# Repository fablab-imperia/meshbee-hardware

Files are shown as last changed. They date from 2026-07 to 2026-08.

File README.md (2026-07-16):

# 🐝 MeshBee - Sistema di Monitoraggio Arnie

Hardware

```
meshbee-hardware/
├── 3d-print/     # File CAD per stampa 3D (FreeCAD)
└── pcb/          # Schemi elettrici e documentazione
```

## 📄 Licenza

Questo progetto è distribuito sotto licenza CERN-OHL-S

## 👥 Team

Sviluppato per apicoltori e monitoraggio ambientale.

---

**Fatto con ❤️ per le api** 🐝

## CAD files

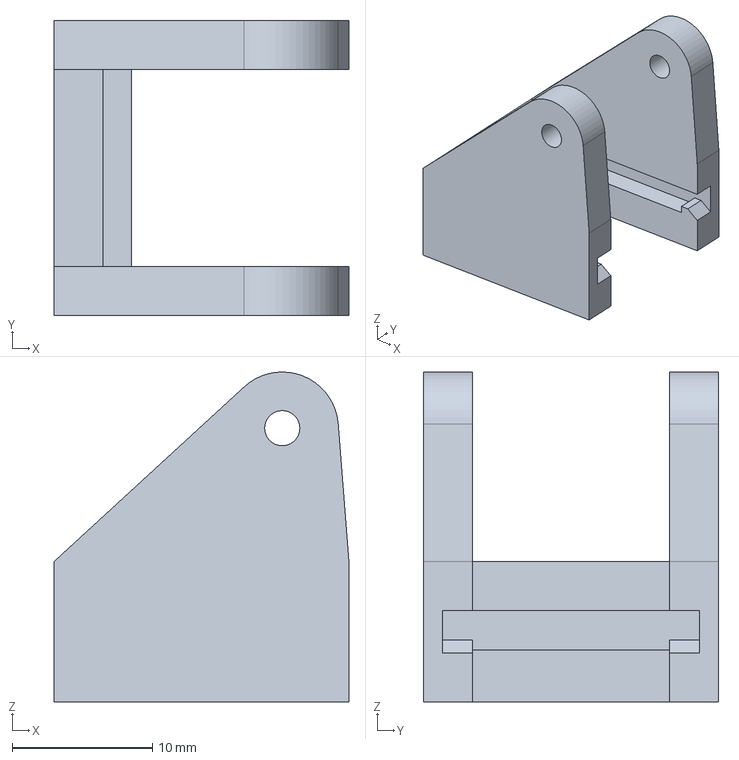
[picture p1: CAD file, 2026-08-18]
3d-print/sensor.FCStd
21.0 x 21.0 x 23.5 mm

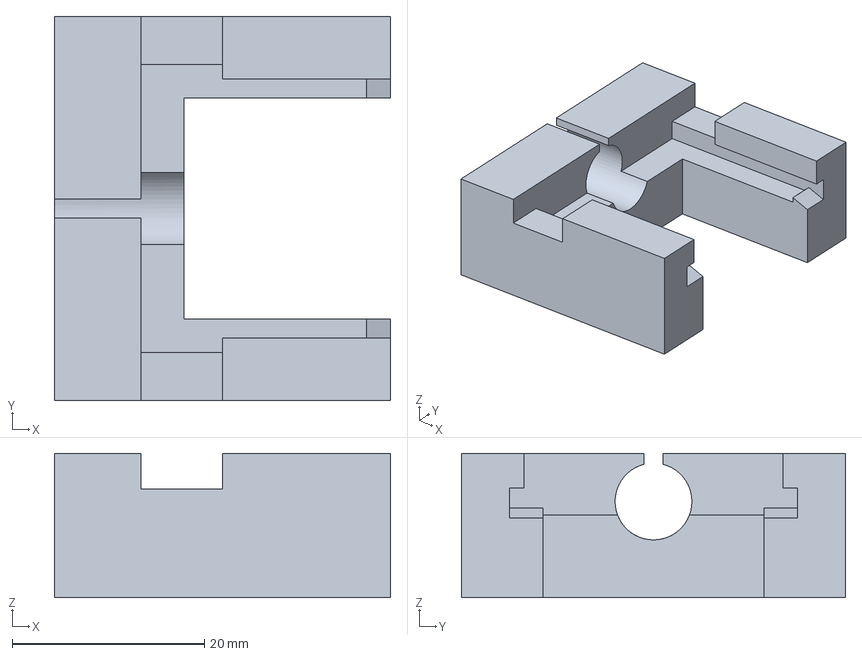
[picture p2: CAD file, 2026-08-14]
3d-print/cell_holder.FCStd
35.0 x 40.0 x 15.0 mm

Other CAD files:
3d-print/beehive modules.FCStd

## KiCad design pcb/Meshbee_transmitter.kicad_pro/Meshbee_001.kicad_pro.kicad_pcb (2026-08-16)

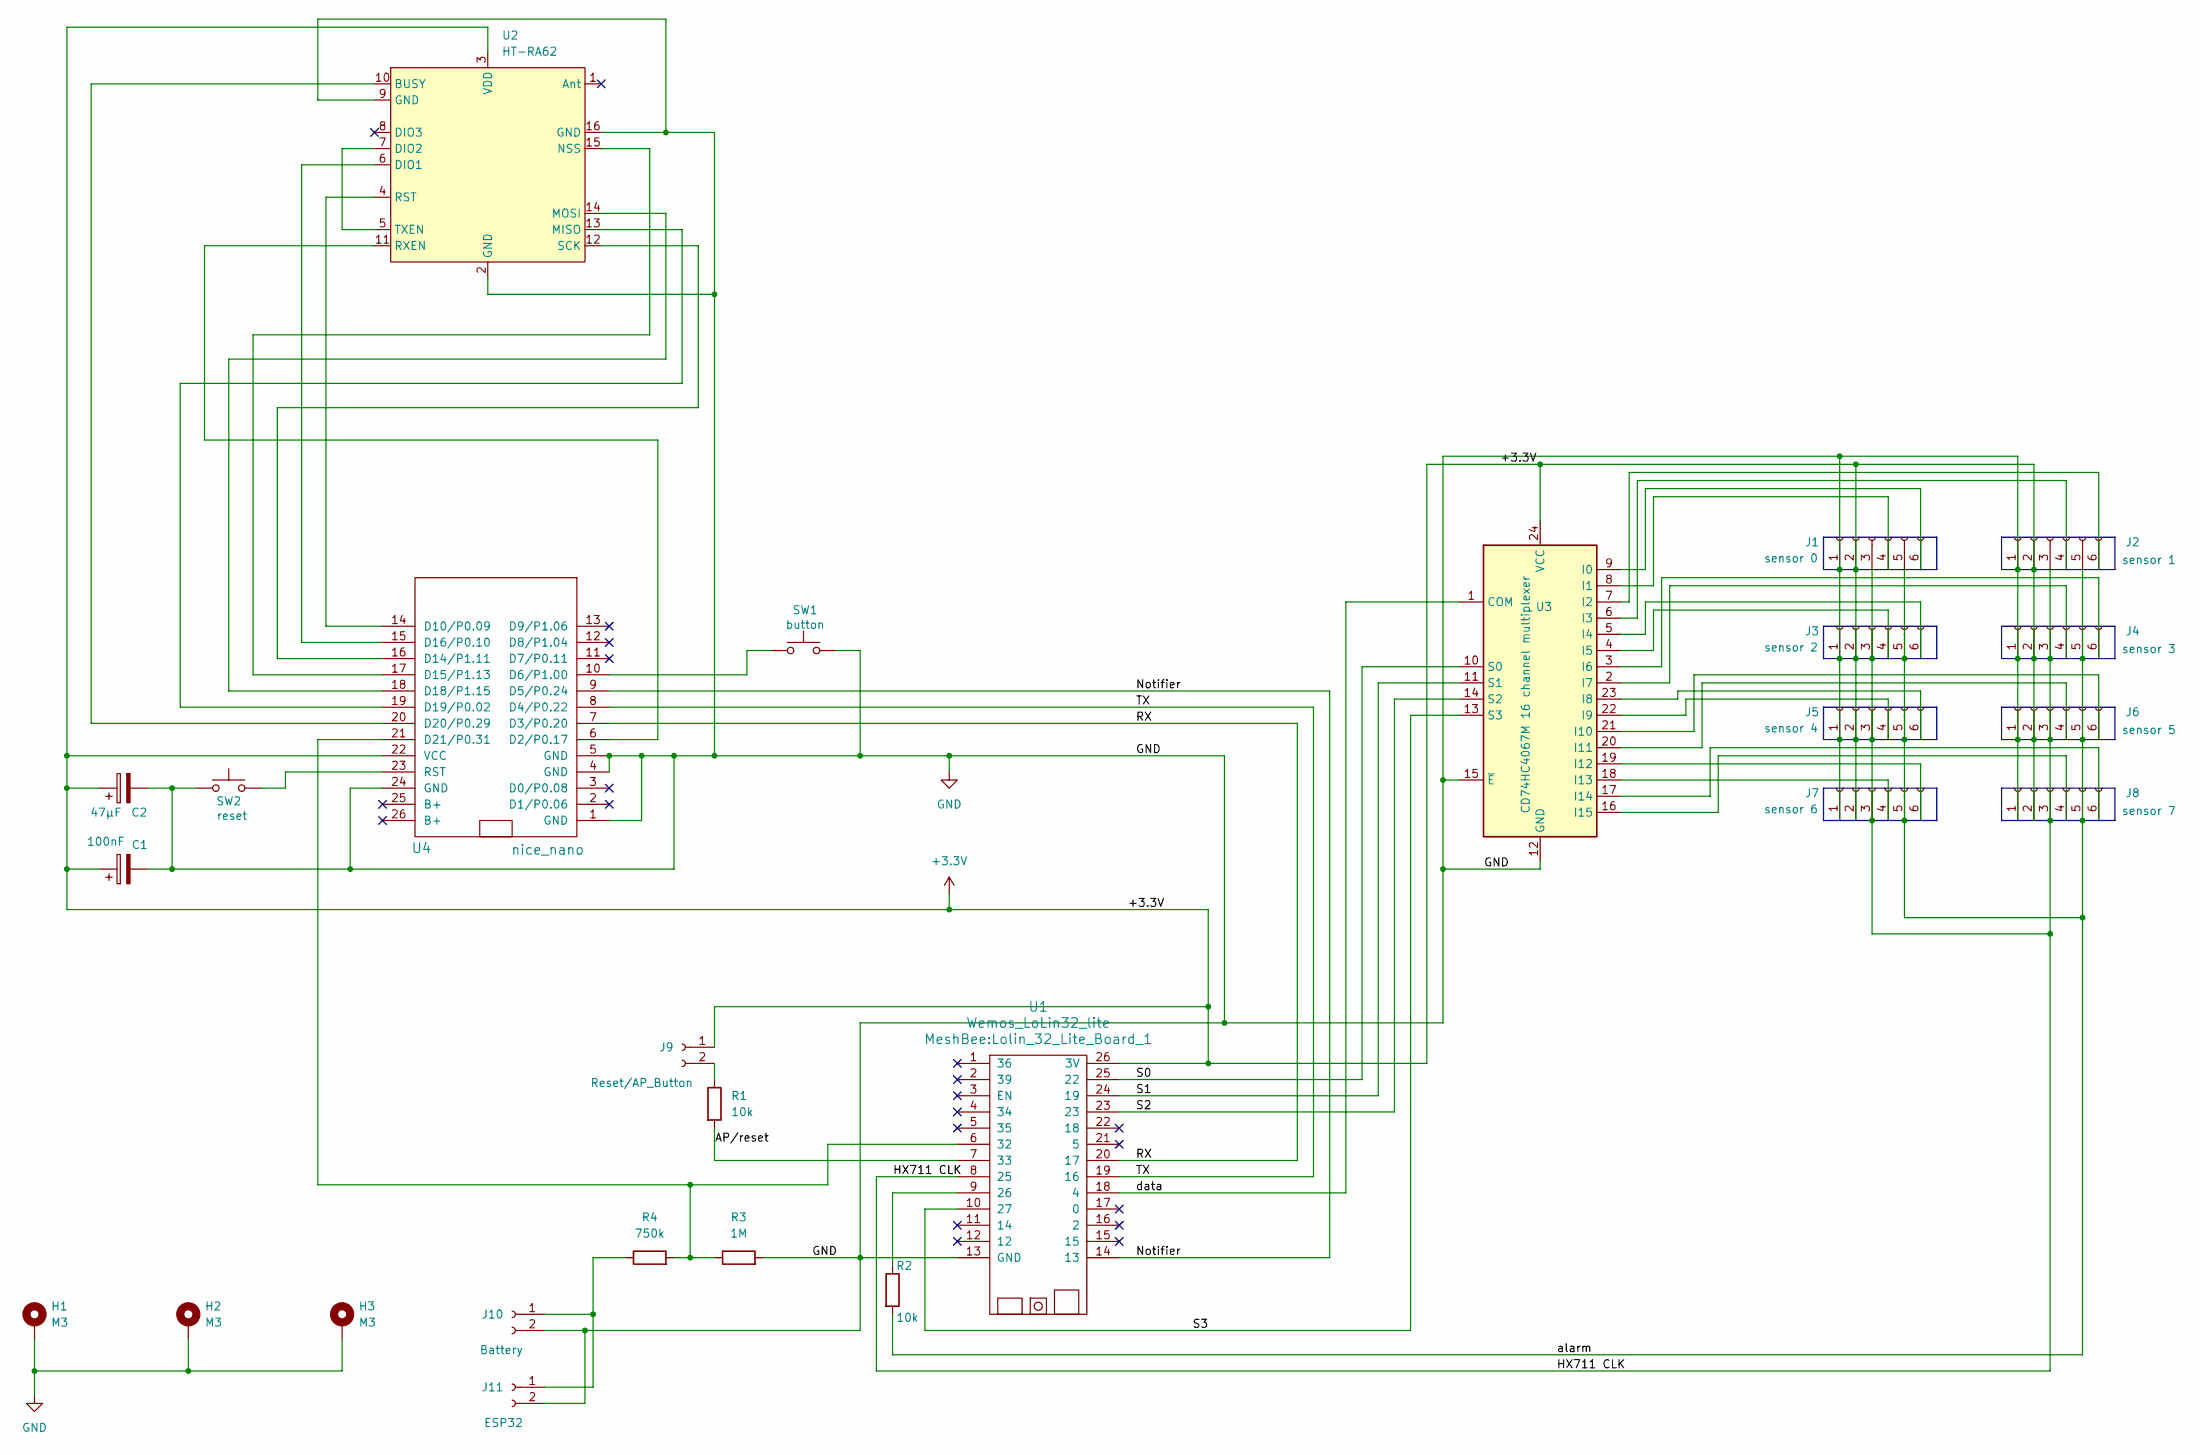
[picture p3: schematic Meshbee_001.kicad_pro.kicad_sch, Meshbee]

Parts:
C1: 100nF; CP_Radial_Tantal_D5.0mm_P2.50mm
C2: 47µF; CP_Radial_D5.0mm_P2.00mm
H1, H2, H3: M3; MountingHole_3.2mm_M3_DIN965_Pad
J1: sensor 0; MeshBee_JST_XH_B6B-XH-A_1x06_P2.50mm_Vertical
J2: sensor 1; MeshBee_JST_XH_B6B-XH-A_1x06_P2.50mm_Vertical
J3: sensor 2; MeshBee_JST_XH_B6B-XH-A_1x06_P2.50mm_Vertical
J4: sensor 3; MeshBee_JST_XH_B6B-XH-A_1x06_P2.50mm_Vertical
J5: sensor 4; MeshBee_JST_XH_B6B-XH-A_1x06_P2.50mm_Vertical
J6: sensor 5; MeshBee_JST_XH_B6B-XH-A_1x06_P2.50mm_Vertical
J7: sensor 6; MeshBee_JST_XH_B6B-XH-A_1x06_P2.50mm_Vertical
J8: sensor 7; MeshBee_JST_XH_B6B-XH-A_1x06_P2.50mm_Vertical
J9: Reset/AP_Button; JST_XH_B2B-XH-A_1x02_P2.50mm_Vertical
J10: Battery; JST_XH_B2B-XH-A_1x02_P2.50mm_Vertical
J11: ESP32; JST_XH_B2B-XH-A_1x02_P2.50mm_Vertical
R1, R2: 10k; R_Axial_DIN0204_L3.6mm_D1.6mm_P7.62mm_Horizontal
R3: 1M; R_1206_3216Metric_Pad1.30x1.75mm_HandSolder
R4: 750k; R_1206_3216Metric_Pad1.30x1.75mm_HandSolder
SW1: button
SW2: reset; button
U1: Wemos_LoLin32_lite; Lolin_32_Lite_Board_1
U2: HT-RA62
U3: CD74HC4067M 16 channel multiplexer
U4: nice_nano

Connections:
+3.3V: C1.1, C2.1, J1.2, J2.2, J3.2, J4.2, J5.2, J6.2, J7.2, J8.2, J9.1, U1.26 (3V), U2.3 (VDD), U3.24 (VCC), U4.22 (VCC)
/AP/reset: R1.2, U1.7 (33)
/HX711 CLK: J1.3, J2.3, J3.3, J4.3, J5.3, J6.3, J7.3, J8.3, U1.8 (25)
/Notifier: U1.14 (13), U4.9 (D5/P0.24)
/RX: U1.20 (17), U4.7 (D3/P0.20)
/S0: U1.25 (22), U3.10 (S0)
/S1: U1.24 (19), U3.11 (S1)
/S2: U1.23, U3.14 (S2)
/S3: U1.10 (27), U3.13 (S3)
/TX: U1.19 (16), U4.8 (D4/P0.22)
/alarm: J1.5, J2.5, J3.5, J4.5, J5.5, J6.5, J7.5, J8.5, R2.2
/data: U1.18 (4), U3.1 (COM)
GND: C1.2, C2.2, H1.1 (1_1), H2.1 (1_1), H3.1 (1_1), J1.1, J2.1, J3.1, J4.1, J5.1, J6.1, J7.1, J8.1, J10.2, J11.2, R3.2, SW1.2, SW2.1, U1.13 (GND), U2.2 (GND), U2.9 (GND), U2.16 (GND), U3.12 (GND), U3.15 (~E), U4.1 (GND), U4.4 (GND), U4.5 (GND), U4.24 (GND)
unnamed: J1.4, U3.8 (I1)
unnamed: J1.6, U3.9 (I0)
unnamed: J2.4, U3.6 (I3)
unnamed: J2.6, U3.7 (I2)
unnamed: J3.4, U3.4 (I5)
unnamed: J3.6, U3.5 (I4)
unnamed: J4.4, U3.2 (I7)
unnamed: J4.6, U3.3 (I6)
unnamed: J5.4, U3.22 (I9)
unnamed: J5.6, U3.23 (I8)
unnamed: J6.4, U3.20 (I11)
unnamed: J6.6, U3.21 (I10)
unnamed: J7.4, U3.18 (I13)
unnamed: J7.6, U3.19 (I12)
unnamed: J8.4, U3.16 (I15)
unnamed: J8.6, U3.17 (I14)
unnamed: J9.2, R1.1
unnamed: J10.1, J11.1, R4.1
unnamed: R2.1, U1.9 (26)
unnamed: R3.1, R4.2, U1.6 (32), U4.21 (D21/P0.31)
unnamed: U2.10 (BUSY), U4.20 (D20/P0.29)
unnamed: U2.6 (DIO1), U4.15 (D16/P0.10)
unnamed: U2.5 (TXEN), U2.7 (DIO2)
unnamed: U2.13 (MISO), U4.19 (D19/P0.02)
unnamed: U2.14 (MOSI), U4.18 (D18/P1.15)
unnamed: U2.15 (NSS), U4.17 (D15/P1.13)
unnamed: U2.4 (RST), U4.14 (D10/P0.09)
unnamed: U2.11 (RXEN), U4.6 (D2/P0.17)
unnamed: U2.12 (SCK), U4.16 (D14/P1.11)
unnamed: SW1.1, U4.10 (D6/P1.00)
unnamed: SW2.2, U4.23 (RST)

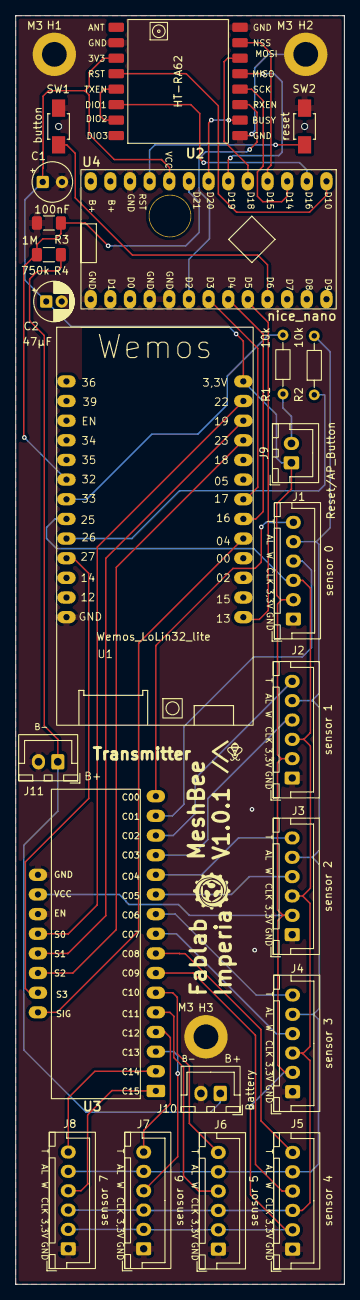
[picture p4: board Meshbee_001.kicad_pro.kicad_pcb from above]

Board: 2 copper layers, 42.5 x 164.0 mm, 26 parts (0 on the bottom side), 44 nets.

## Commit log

2026-05-25 refactor: reorganize project structure and naming conventions
    [arnia-module-v1.FCStd, arnia-module-v2.FCStd, faketec-esp32-pinout.xlsx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]
2026-07-23 Added transmitter PCB in KiCAD
    [Meshbee_001.kicad_pro-B_Cu.gbr, Meshbee_001.kicad_pro-B_Mask.gbr, Meshbee_001.kicad_pro-B_Paste.gbr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]
2026-07-23 Added Receiver in KiCAD
    [Meshbee_001.kicad_pro.kicad_pcb, Meshbee_001.kicad_pro.kicad_sch]
2026-07-23 Added ZIP-file with Gerber files and drill files
    [Meshbee_001.kicad_pro-B_Cu.gbr, Meshbee_001.kicad_pro-B_Mask.gbr, Meshbee_001.kicad_pro-B_Paste.gbr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]
2026-07-23 addedd plot and drill files
    [Meshbee_001.kicad_pro-B_Cu.gbr, Meshbee_001.kicad_pro-B_Mask.gbr, Meshbee_001.kicad_pro-B_Paste.gbr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]
2026-07-23 added mounting manual for receiver and transmitter
    [faketec-esp32-pinout.xlsx]
2026-07-23 added BOM
    [BOM 2026 04 16.xlsx]
2026-07-23 renewed print files
    [sensor.FCStd]
2026-07-23 added print files
    [arnia-module-v1.FCStd, arnia-module-v2.FCStd, beehive modules.FCStd]
2026-07-28 replotted files
    [Meshbee_001.kicad_pro-Edge_Cuts.gbr]
2026-08-06 - transferred some markings on the board to silkscreen layer - renumeration of WEMOS LOLIN32 LITE Pins - modified 3D-printed module for battery - created 3D-print module for MeshBee PCB
    [Meshbee_001.kicad_pro-B_Cu.gbr, Meshbee_001.kicad_pro-B_Mask.gbr, Meshbee_001.kicad_pro-B_Paste.gbr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]
2026-08-11 - minor changes on silkscreen - added sensor circuit - added 3D-print designs for load cell holders
    [Meshbee_001.kicad_pro-B_Cu.gbr, Meshbee_001.kicad_pro-B_Mask.gbr, Meshbee_001.kicad_pro-B_Paste.gbr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]
2026-08-12 - added possibility to measure battery voltage with the ESP32 to transmit to database
    [Meshbee_001.kicad_pro.kicad_pcb, Meshbee_001.kicad_pro.kicad_sch]
2026-08-14 - changed load cell holder design - changed some labels in the circuit
    [Meshbee_001.kicad_pro.kicad_sch, cell_holder.FCStd, sensor.FCStd]
2026-08-16 - added capacitor on NRF52480 power lines, for possible crashes of nrf52840 during switch from solar panel to battery due to power glitches - changed GPIO of S3 pin of multiplexer to use GPIO22 for i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
    [Meshbee_001.kicad_pro-B_Cu.gbr, Meshbee_001.kicad_pro-B_Mask.gbr, Meshbee_001.kicad_pro-B_Paste.gbr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]
2026-08-18 - sorted out 3d print parts
    [sensor.FCStd]
